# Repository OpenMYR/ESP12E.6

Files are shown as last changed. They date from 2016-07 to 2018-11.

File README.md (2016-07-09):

IoT Motor Hardware: Stepper
==============================
by OpenMYR

[OpenMYR Homepage](http://www.OpenMYR.com/)

Software by Brandon Brown and Kyle Berezin

Hardware design by Chris Adams

Hardware licensed under CERN Hardware License Version 1.2

Software licensed under MIT License

This repository is the source files for hardware designed to drive a stepper motor with an ESP8266-based platform.

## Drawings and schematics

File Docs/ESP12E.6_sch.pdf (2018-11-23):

A

A

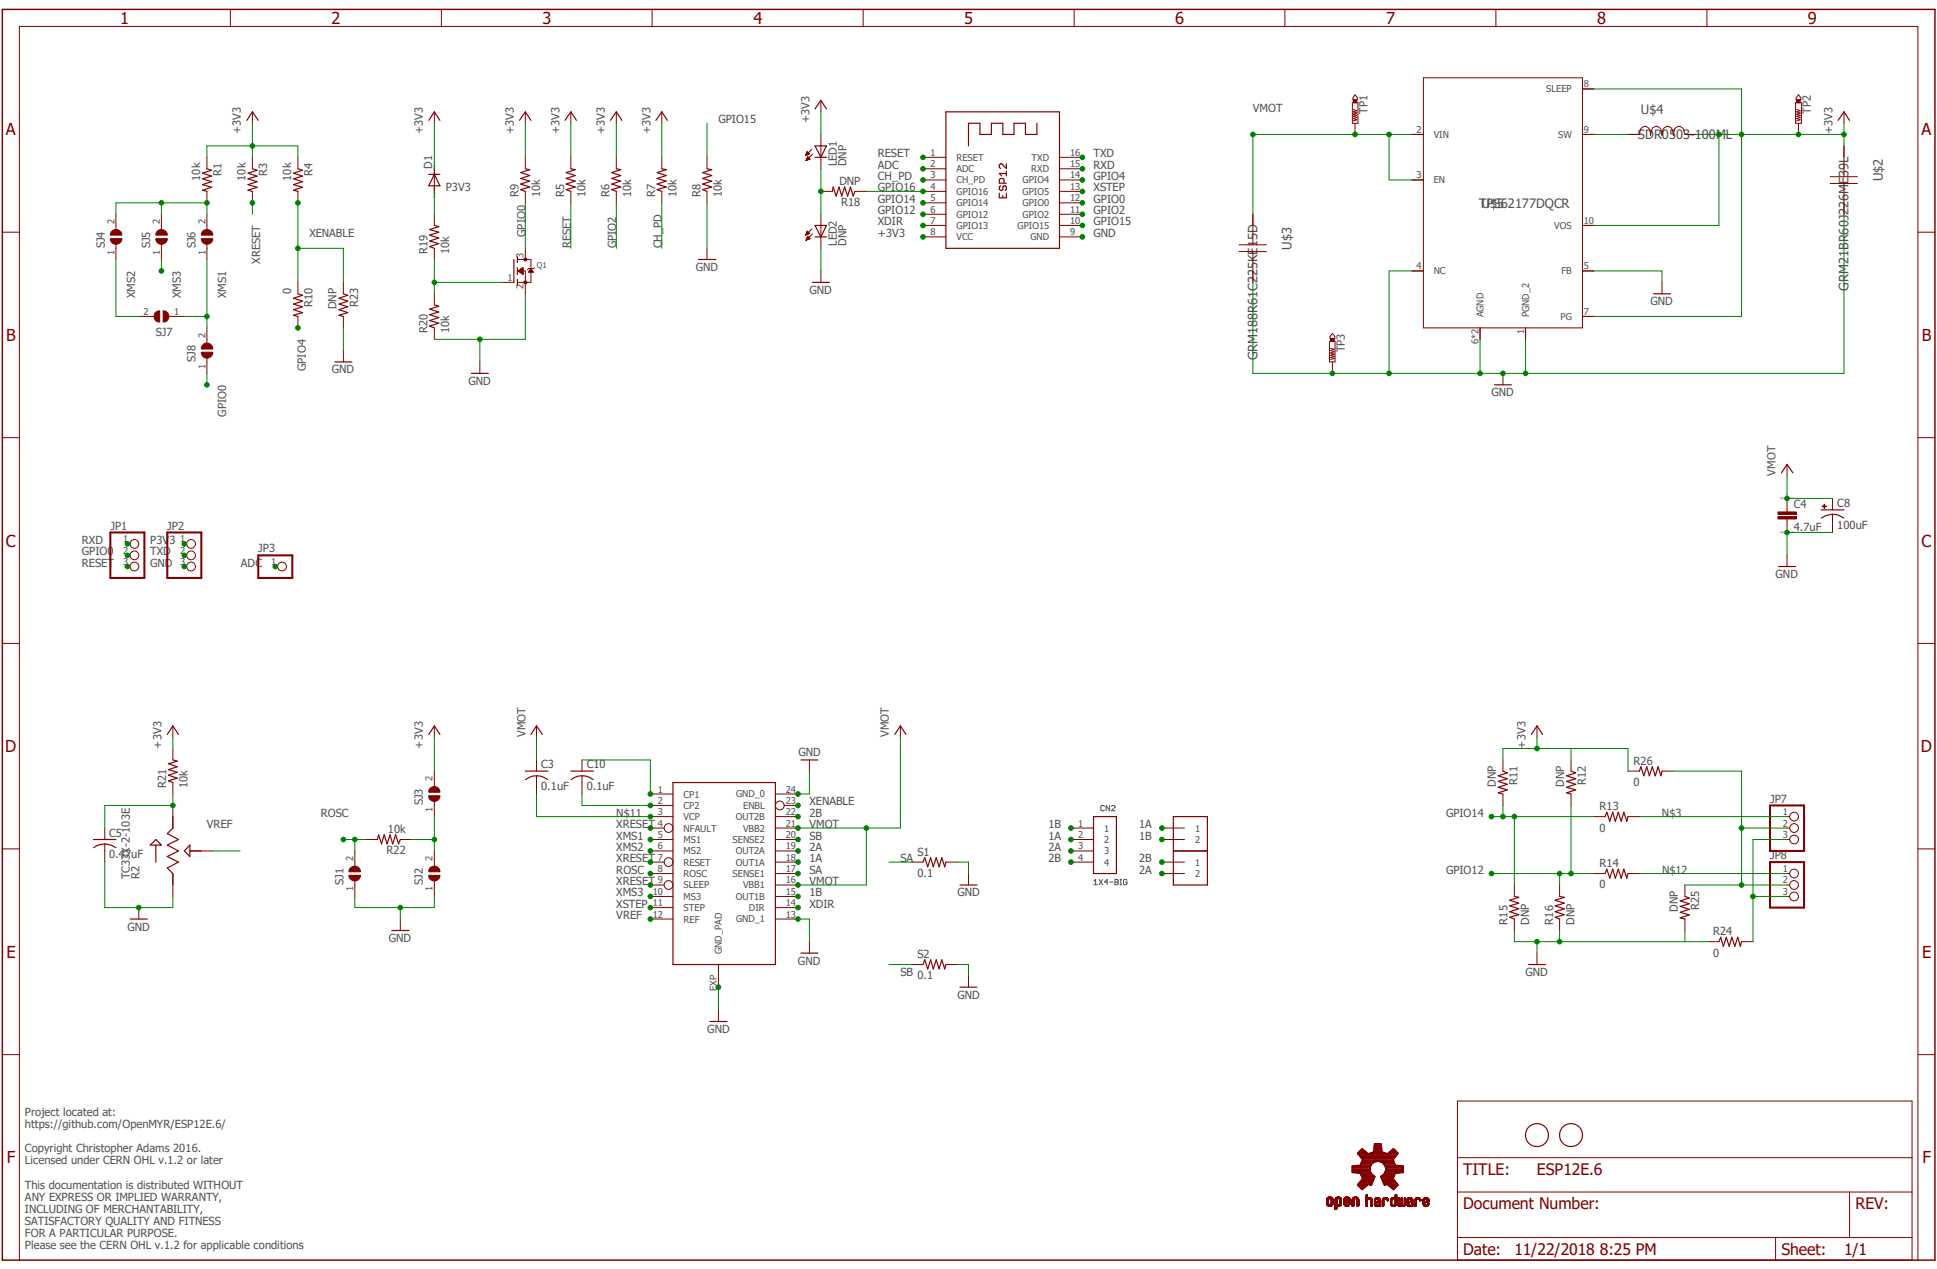
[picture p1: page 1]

SpiceOrder 1 SpiceOrder 2

Project located at: https://github.com/OpenMYR/ESP12E.6/ Copyright Christopher Adams 2016. Licensed under CERN OHL v.1.2 or later This documentation is distributed WITHOUT ANY EXPRESS OR IMPLIED WARRANTY, INCLUDING OF MERCHANTABILITY, SATISFACTORY QUALITY AND FITNESS FOR A PARTICULAR PURPOSE. Please see the CERN OHL v.1.2 for applicable conditions

Document Number: | REV:

Date: 11/22/2018 8:25 PM | Sheet: 1/1

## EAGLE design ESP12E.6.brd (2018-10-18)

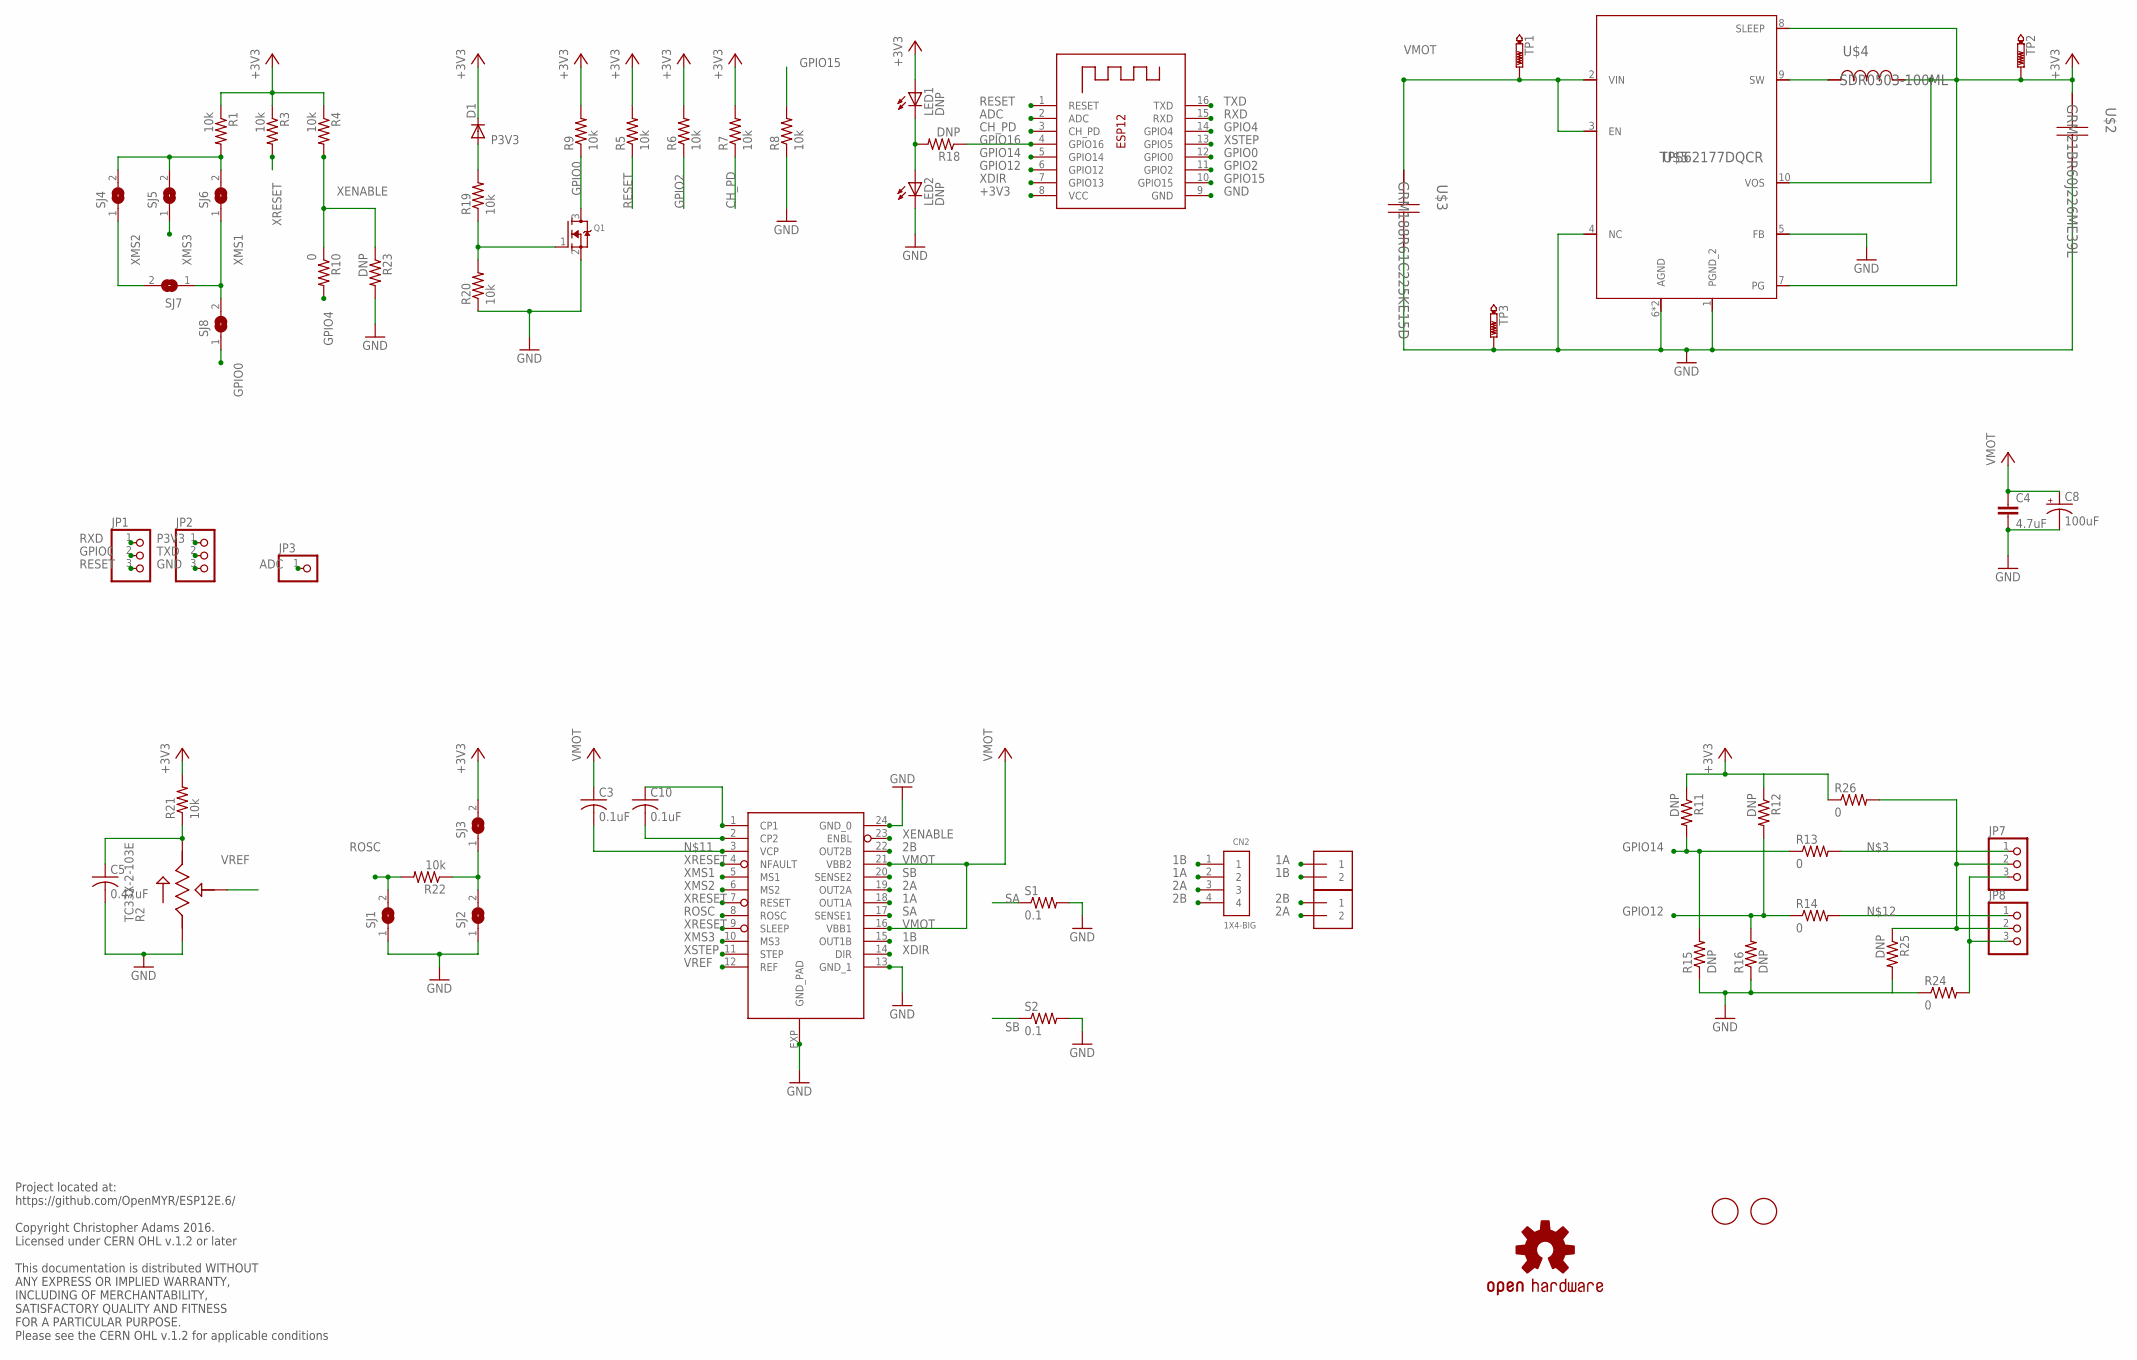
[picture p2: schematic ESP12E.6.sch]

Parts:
C3, C10: 0.1uF; C0603K
C4: 4.7uF; C0805
C5: 0.47uF; C0603K
C8: 100uF; PANASONIC_D
CN2: 1X4-BIG; 1X04-BIG
D1: DIODE-DO214AC; DO214AC
FD1, FD2: FIDUCIAL; FIDUCIAL_1MM
J1, J4: 1X2-3.5MM
JP1, JP2, JP7, JP8: PINHD-1X3; 1X03
JP3: PINHD-1X1CB; 1X01-CLEANBIG
LED1, LED2: DNP; CHIPLED_0603
LOGO1: OSHW-LOGOMINI; OSHW-LOGO-MINI
Q1: MOSFET-NREFLOW; SOT23
R1, R3, R4, R5, R6, R7, R8, R9, R19, R20, R21, R22: 10k; R0603
R2: TC33X-2-103E; 35WR
R10, R13, R14, R24, R26: 0; R0603
R11, R12, R15, R16, R18, R23, R25: DNP; R0603
S1, S2: 0.1; M0805
SJ1, SJ2, SJ3, SJ4, SJ5, SJ6, SJ7, SJ8: SJ
TP1, TP2, TP3: PTR1B1,27; B1,27
U1: A5984; TSSOP-28
U$2: GRM21BR60J226ME39L; 0805
U$3: GRM188R61C225KE15D; 0603
U$4: SDR0503-100ML; SDR0503
U$5: TPS62177DQCR; R-PWSON-N10
X1: ESP-12

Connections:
1A: CN2.2, J4.1, U1.18 (OUT1A)
1B: CN2.1, J4.2, U1.15 (OUT1B)
2A: CN2.3, J1.2, U1.19 (OUT2A)
2B: CN2.4, J1.1, U1.22 (OUT2B)
+3V3: D1.C, LED1.A, R1.1, R3.1, R4.1, R5.2, R6.2, R7.2, R9.2, R11.1, R12.1, R21.2, R26.1, SJ3.2, TP2.TP, U$2.2, U$4.2, U$5.7 (PG), U$5.8 (SLEEP), U$5.10 (VOS), X1.8 (VCC)
ADC: JP3.1, X1.2 (ADC)
CH_PD: R7.1, X1.3 (CH_PD)
GND: C4.2, C5.2, C8.-, JP2.3, LED2.C, Q1.2 (S), R2.1, R8.1, R15.1, R16.1, R20.1, R23.2, R24.1, R25.2, S1.2, S2.2, SJ1.1, SJ2.1, TP3.TP, U1.13 (GND_1), U1.24 (GND_0), U1.EXP (GND_PAD), U$2.1, U$3.1, U$5.1 (PGND_2), U$5.4 (NC), U$5.5 (FB), U$5.6 (AGND), U$5.11 (AGND), X1.9 (GND)
GPIO0: JP1.2, Q1.3 (D), R9.1, SJ8.1, X1.12 (GPIO0)
GPIO2: R6.1, X1.11 (GPIO2)
GPIO4: R10.2, X1.14 (GPIO4)
GPIO12: R12.2, R14.1, R16.2, X1.6 (GPIO12)
GPIO14: R11.2, R13.1, R15.2, X1.5 (GPIO14)
GPIO15: R8.2, X1.10 (GPIO15)
GPIO16: R18.1, X1.4 (GPIO16)
MSN: R1.2, SJ4.2, SJ5.2, SJ6.2
unnamed: C5.1, R2.3, R21.1
unnamed: R22.1, SJ2.2, SJ3.1
unnamed: JP7.1, R13.2
unnamed: LED1.C, LED2.A, R18.2
unnamed: C10.1, U1.1 (CP1)
unnamed: Q1.1 (G), R19.1, R20.2
unnamed: C10.2, U1.2 (CP2)
unnamed: JP7.3, JP8.3, R24.2
unnamed: JP7.2, JP8.2, R25.1, R26.2
unnamed: C3.2, U1.3 (VCP)
unnamed: JP8.1, R14.2
unnamed: U$4.1, U$5.9 (SW)
P3V3: D1.A, JP2.1, R19.2
RESET: JP1.3, R5.1, X1.1 (RESET)
ROSC: R22.2, SJ1.2, U1.8 (ROSC)
RXD: JP1.1, X1.15 (RXD)
SA: S1.1, U1.17 (SENSE1)
SB: S2.1, U1.20 (SENSE2)
TXD: JP2.2, X1.16 (TXD)
VMOT: C3.1, C4.1, C8.+, TP1.TP, U1.16 (VBB1), U1.21 (VBB2), U$3.2, U$5.2 (VIN), U$5.3 (EN)
VREF: R2.2, U1.12 (REF)
XDIR: U1.14 (DIR), X1.7 (GPIO13)
XENABLE: R4.2, R10.1, R23.1, U1.23 (ENBL)
XMS1: SJ6.1, SJ7.1, SJ8.2, U1.5 (MS1)
XMS2: SJ4.1, SJ7.2, U1.6 (MS2)
XMS3: SJ5.1, U1.10 (MS3)
XRESET: R3.2, U1.4 (NFAULT), U1.7 (RESET), U1.9 (SLEEP)
XSTEP: U1.11 (STEP), X1.13 (GPIO5)

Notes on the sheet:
Project located at: https://github.com/OpenMYR/ESP12E.6/ Copyright Christopher Adams 2016. Licensed under CERN OHL v.1.2 or later This documentation is distributed WITHOUT ANY EXPRESS OR IMPLIED WARRANTY, INCLUDING OF MERCHANTABILITY, SATISFACTORY QUALITY AND FITNESS FOR A PARTICULAR PURPOSE. Pleas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

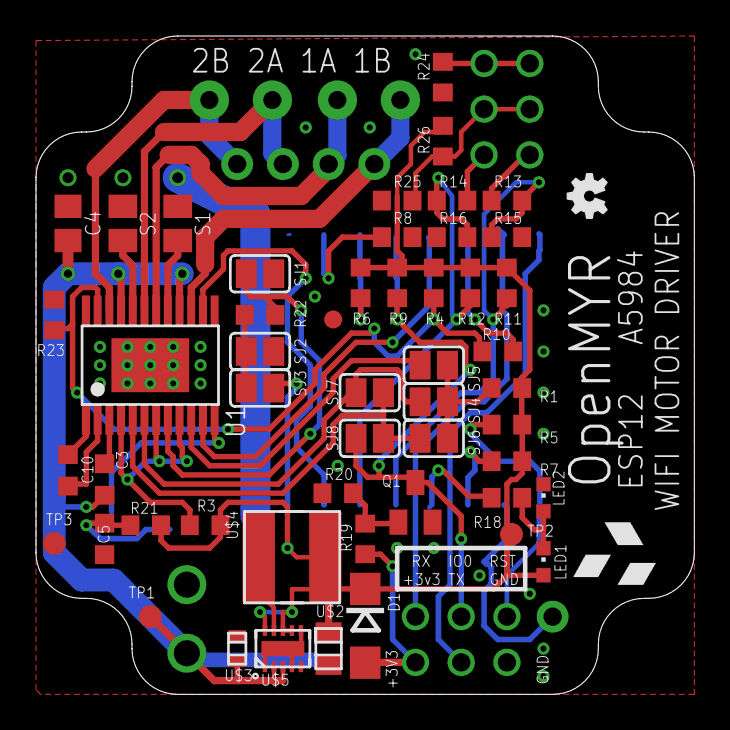
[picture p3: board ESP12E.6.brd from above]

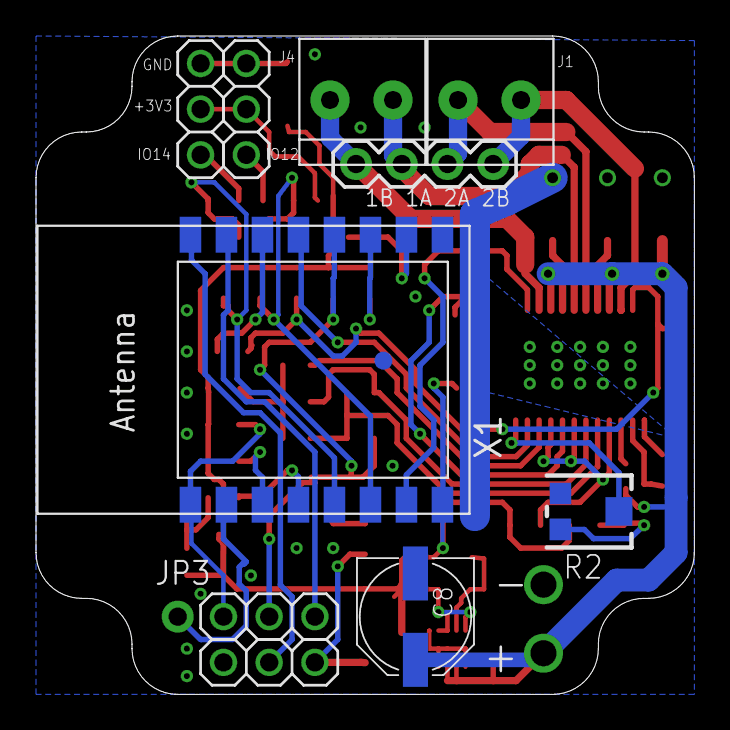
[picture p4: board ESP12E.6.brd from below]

Board: 2 copper layers, 36.6 x 36.6 mm, 64 parts (12 on the bottom side), 44 nets.

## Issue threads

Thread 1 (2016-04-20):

The regulator overheats

brandonbrown2, 2016-04-20:
The linear regulator runs hot due to burning too much power when the ESP8266 is functioning at the higher end of its current usage requirements. This causes the device to reset. This has only been demonstrated when the device is running in softAP broadcast mode, and can be triggered by having more than one client connect to the station. It may take multiple connects and disconnects to trigger it, but it does happen. This does not happen with the servo board because the motor voltage rails of that design are only 5 volts, meaning that only 1.6 volts are burned, as opposed to the 8.6 volts burned with the stepper design.

Vzor-, 2016-04-20:
Confirmed with both of the boards here.

chradams, 2016-05-23:
We will be addressing this issue with a switching regulator for 12VDC powered boards. The regulator has been tested on its own PCB and added to IO-Changes @ 3e671ce91a2bfdb306f3759afbd26d7521569aa6. Issue will be closed once [IO-Changes](https://github.com/OpenMYR/ESP12E.6/tree/IO-Changes) 3e671ce91a2bfdb306f3759afbd26d7521569aa6 is tested.

Vzor-, 2016-05-30:
fixed as of 3e671ce91a2bfdb306f3759afbd26d7521569aa6

Closed 2016-05-30.

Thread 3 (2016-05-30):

Move R3 away from ground pin

chradams, 2016-05-30:

chradams, 2016-08-28:
Fixed in b48cdabea1e8b10baaec010b9a34599482f7d3bd

Closed 2016-08-28.

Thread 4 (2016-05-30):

Change ESP12E solder mask

chradams, 2016-05-30:
Solder mask is ok for SMD process but difficult to access with soldering iron. Pads should extend further out.

chradams, 2016-08-28:
Closing without changes to the board. Solder mask will stay the same.

Closed 2016-08-28.

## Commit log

2016-04-03 First Commit
    Design 6:
    ESP12E with Allegro A5984
    [ESP12E.6.brd, ESP12E.6.sch]
2016-04-06 GPIO pins repurposed
    GPIO 12 and 14 broken out to to pin headers for general use. Required
    that the MS section of board to be modified. GPIO0 now can control step
    mode between 0 and 32 micro-stepping.
    [ESP12E.6.brd, ESP12E.6.sch]
2016-05-08 Buck Regulator
    Prototype +3.3V DC buck regultaor. Based around TI TPS62177 IC.
    [ESP12E.6.brd, ESP12E.6.sch]
2016-07-09 License Update
    Licensed under CERN OHL v.1.2 or later
    [ESP12E.6.brd, ESP12E.6.sch]
2016-08-28 Power Isolation
    Separation between VMOT/+3V3 and +3V3/GND nets is increased. Rearranged
    R3,R21, U$3 and, U$2.
    Removed U$1 in the regulator schematic as it was not nessesary.
    [ESP12E.6.brd, ESP12E.6.sch]
2016-10-15 PDF schematic generated
    PDF schematic added into Docs folder. Sch file modified to have
    schematic more presentable.
    [ESP12E.6.sch]
2018-05-20 //Lowered power via hole sizes to 18 AWG // Added ADC pin exposure
    [ESP12E.6.brd, ESP12E.6.sch]
2018-05-24 PDF schematic updated
2018-10-18 Oct Update
    Power drill size change and placment of IO pin resistors
    [ESP12E.6.brd, ESP12E.6.sch]

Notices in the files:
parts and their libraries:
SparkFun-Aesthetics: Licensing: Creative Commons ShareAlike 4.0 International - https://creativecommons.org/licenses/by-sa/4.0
